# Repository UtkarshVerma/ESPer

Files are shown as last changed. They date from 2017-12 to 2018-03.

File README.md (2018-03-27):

# ESPer

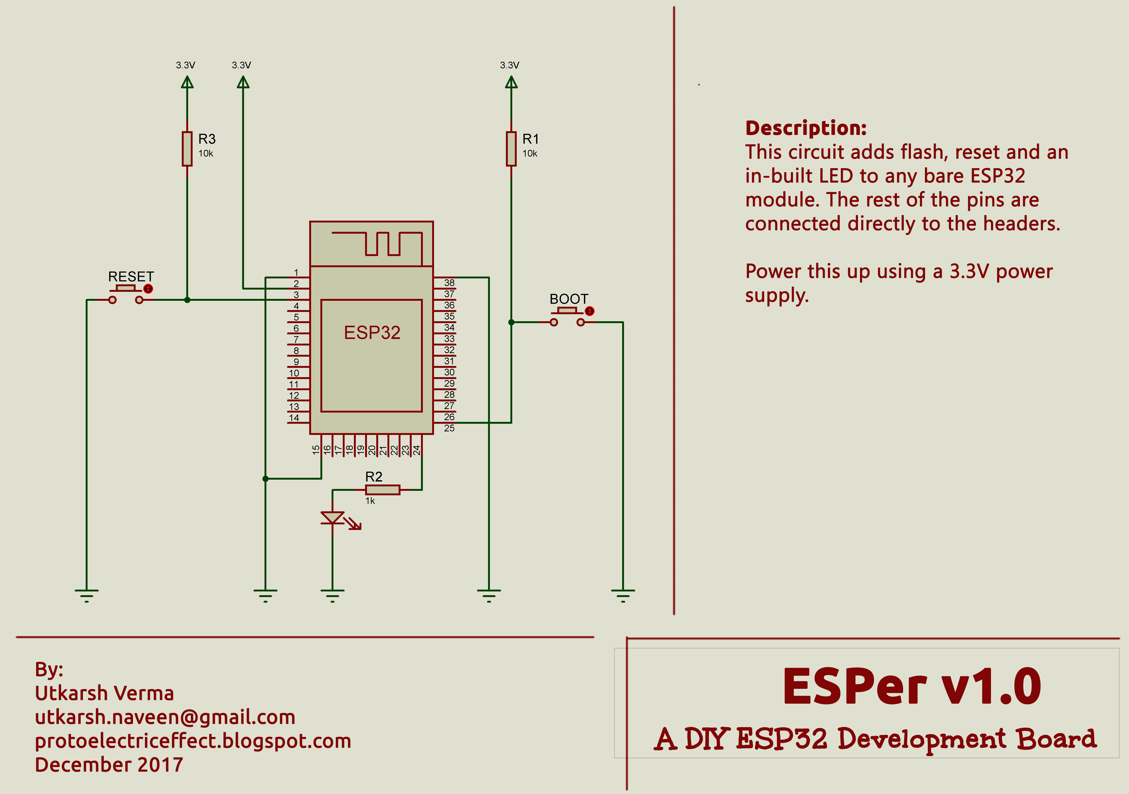
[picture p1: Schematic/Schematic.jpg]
The schematic


ESPer is a DIY ESP32 breakout board which can be easily made at home using commonly available components, because the PCB is one-sided. It 
is also breadboardable, portable and powered through a 3.3V power supply.

This repository is for storing the files related to ESPer Development board. For more info regarding this board, visit:

[DIY ESP32 Development Board - ESPer](https://www.instructables.com/id/DIY-ESP32-Development-Board-ESPer/)

You can also check out its testing video on YouTube:
[ESPer Blink Test](https://youtu.be/wEwncJ5RnA0)

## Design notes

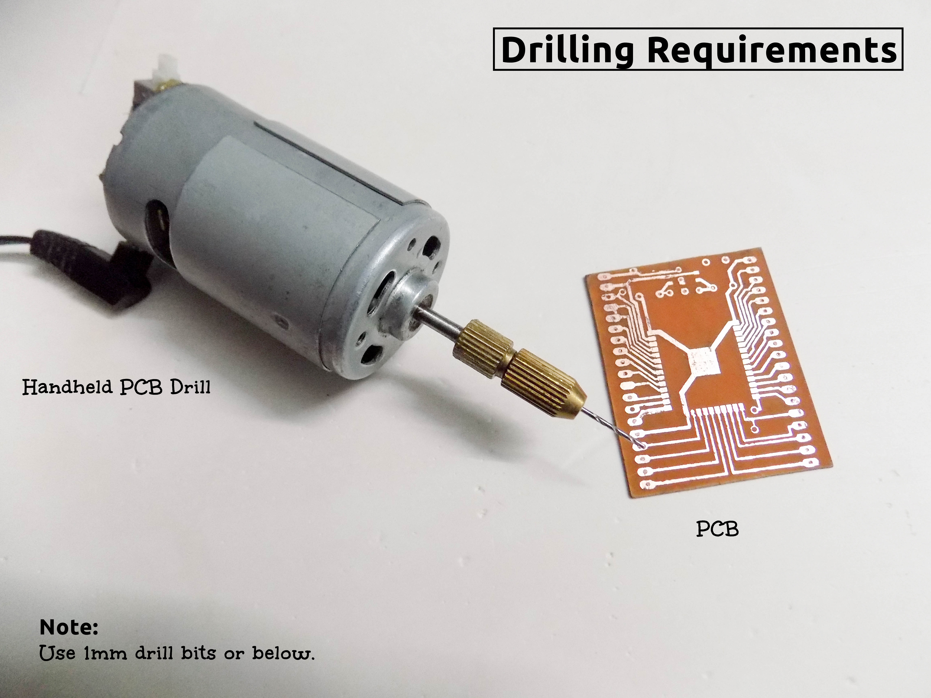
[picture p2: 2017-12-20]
Edited Pictures/Drilling Requirements.jpg

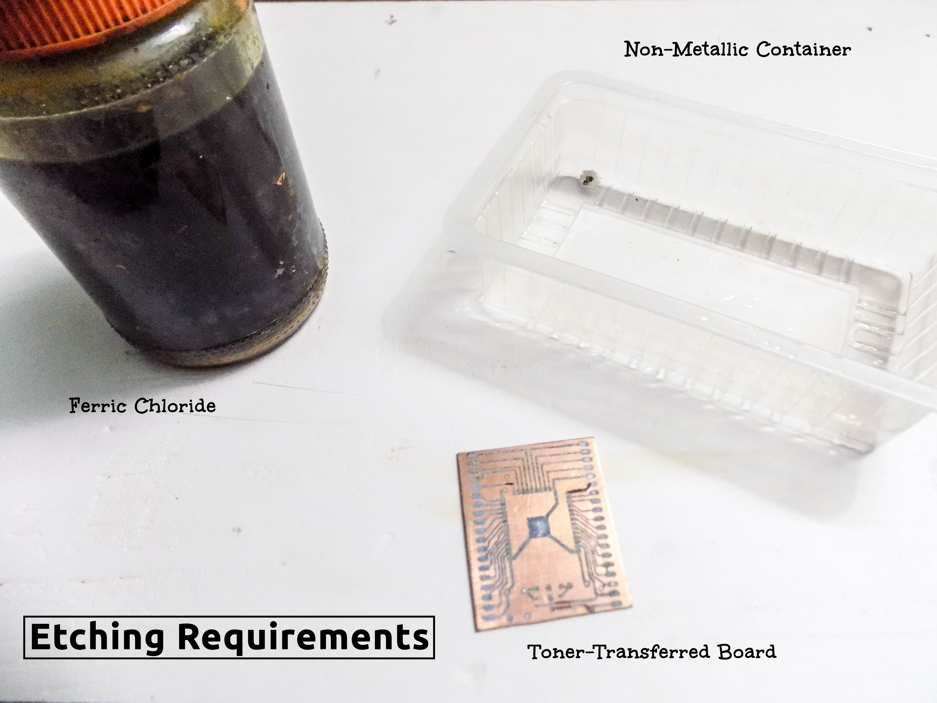
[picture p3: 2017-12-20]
Edited Pictures/Etching Requirements.jpg

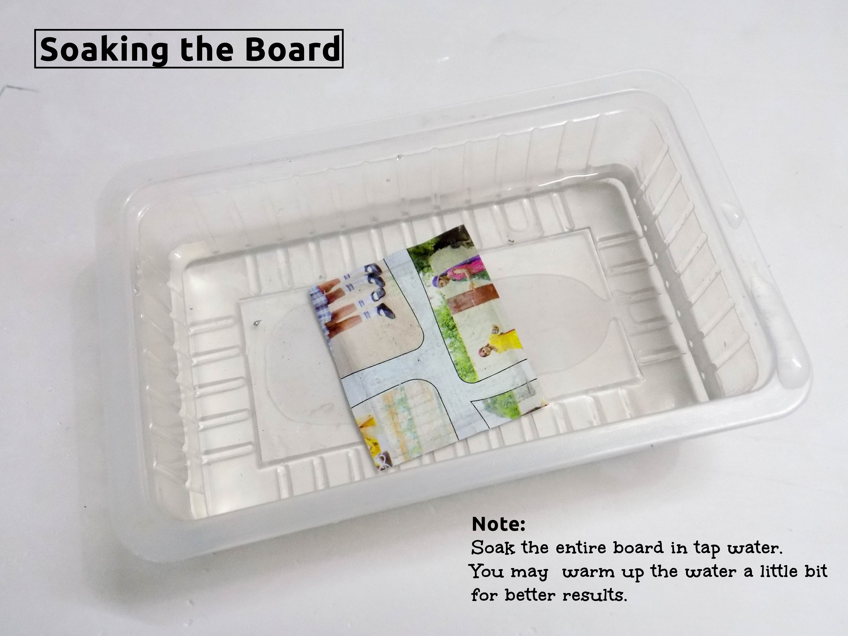
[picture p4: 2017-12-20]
Edited Pictures/Soaking the Board.jpg

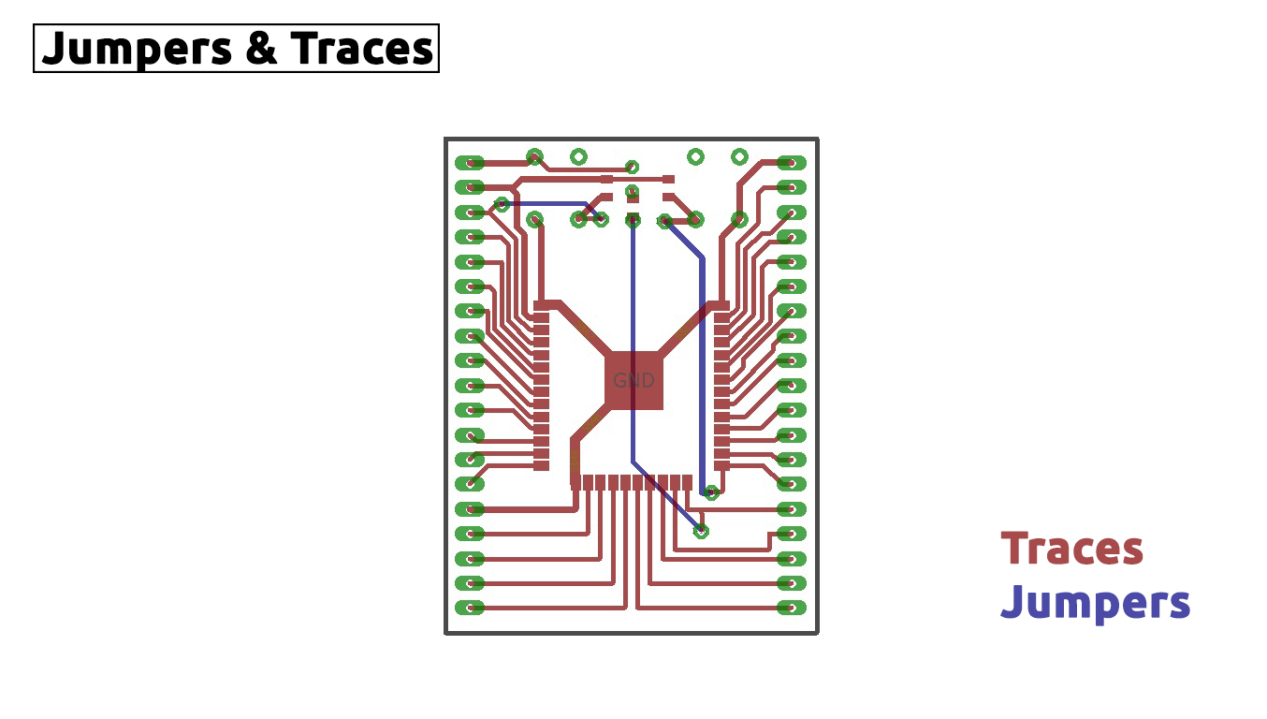
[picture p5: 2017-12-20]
PCB Files/Jumpers & Traces.jpg

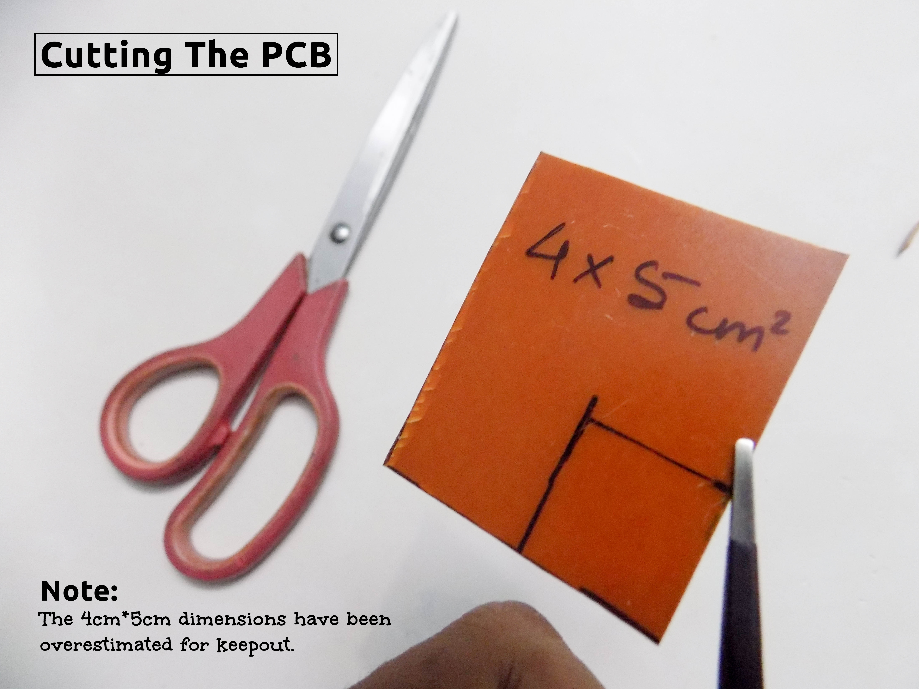
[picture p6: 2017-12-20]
Edited Pictures/Cutting The PCB.jpg

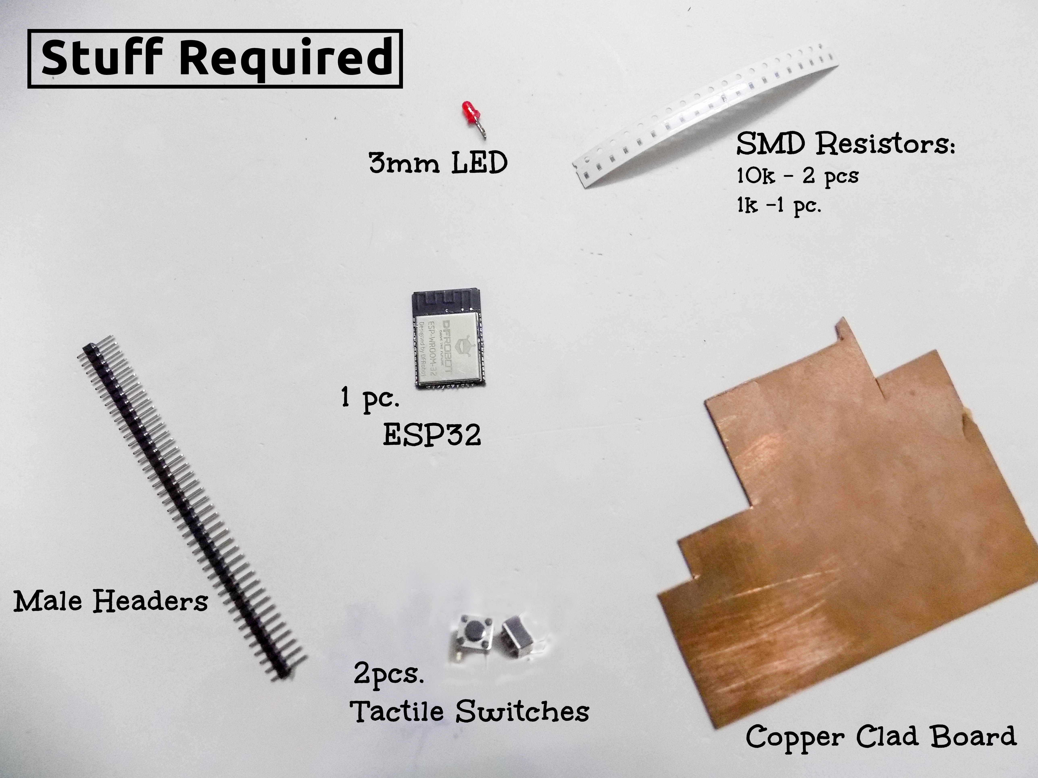
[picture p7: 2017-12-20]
Edited Pictures/Stuff Required.jpg

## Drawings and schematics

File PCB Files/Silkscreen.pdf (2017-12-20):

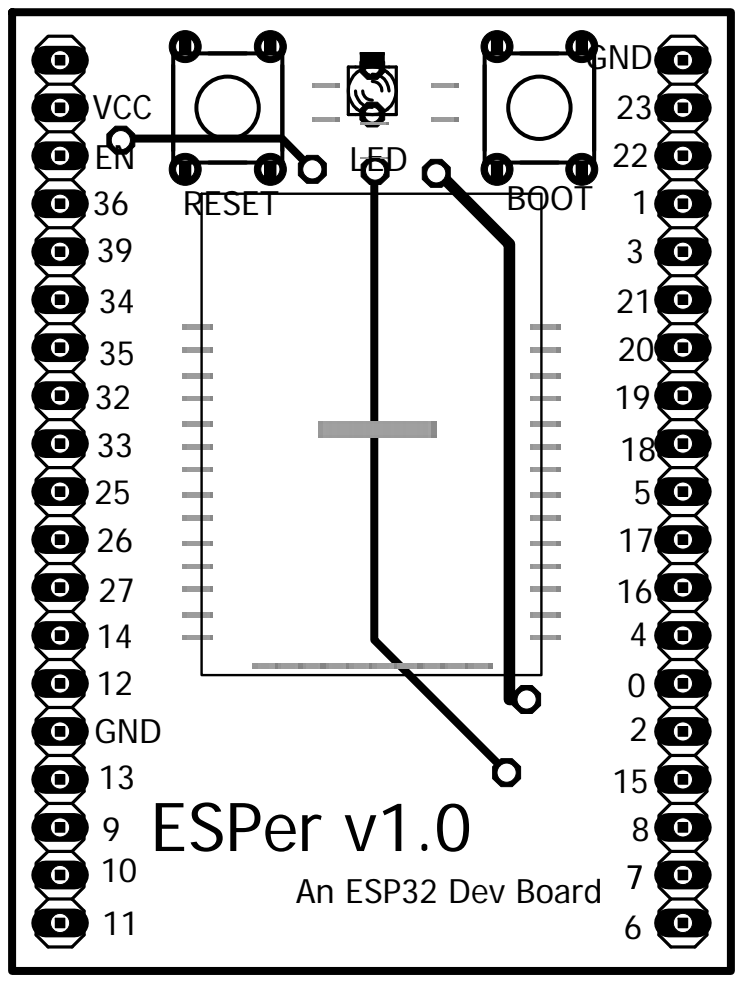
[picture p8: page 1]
VCC EN; 34 35 32 33 25 26 27 14 12 GND 13 9 10; GND; RESET; BOOT; ESPer v1.0; LED

An ESP32 Dev Board

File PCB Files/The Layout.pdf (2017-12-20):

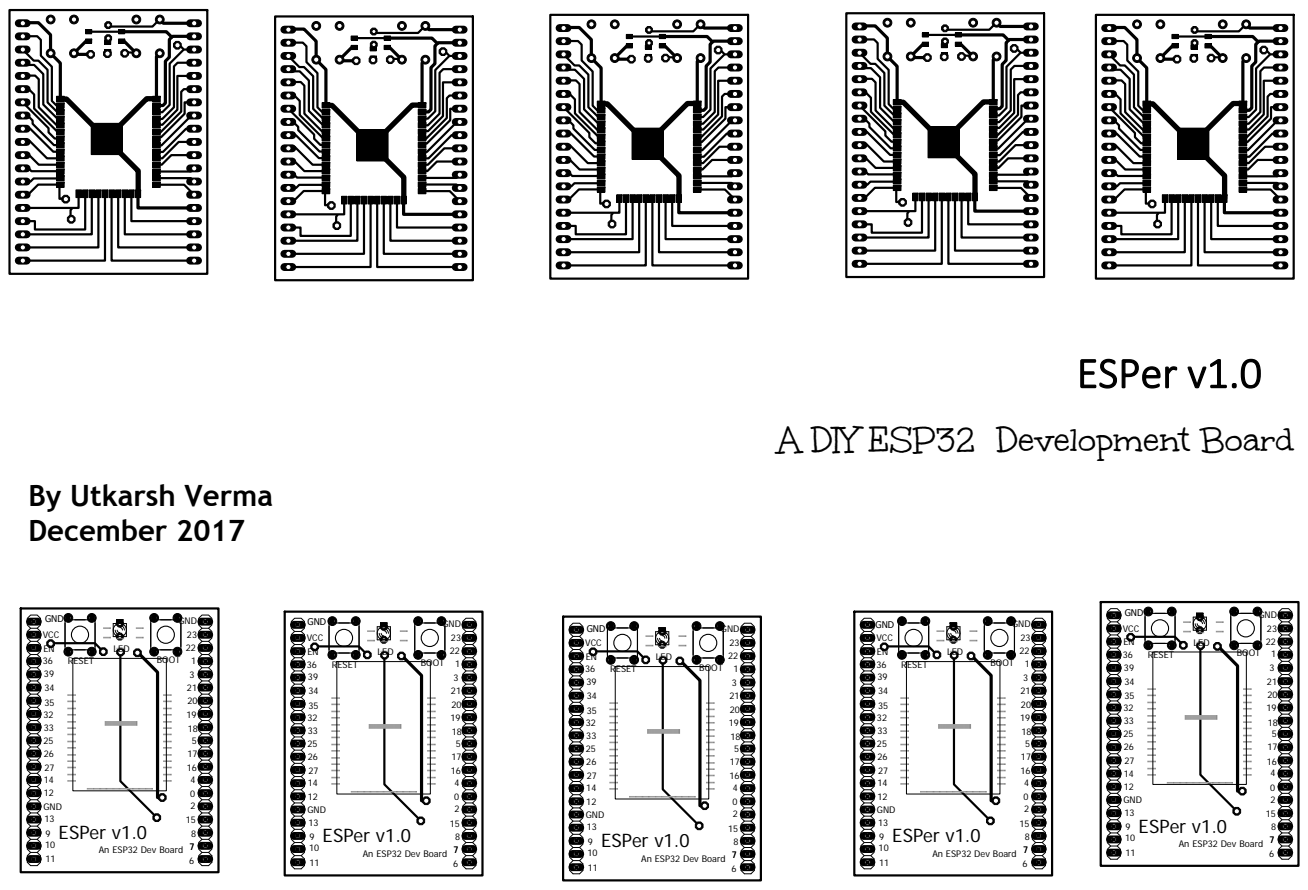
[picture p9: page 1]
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

A DIY ESP32 Development Board

By Utkarsh Verma
December 2017

An ESP32 Dev Board

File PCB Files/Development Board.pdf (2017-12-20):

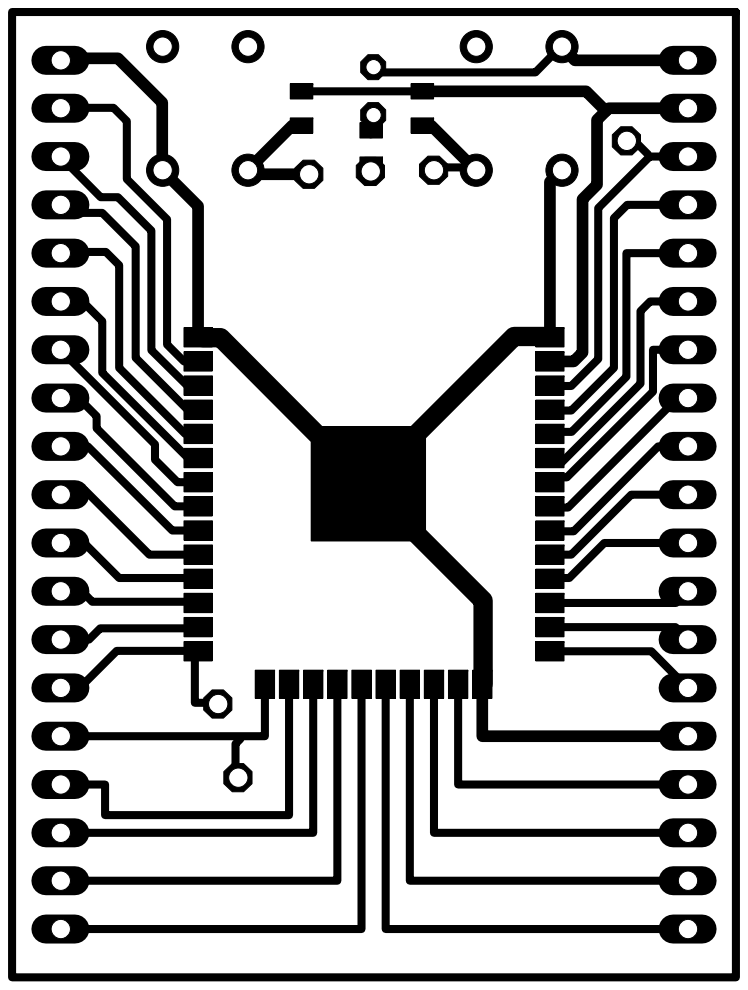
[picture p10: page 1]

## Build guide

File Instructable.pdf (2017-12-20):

instructables

## DIY ESP32 Development Board - ESPer

by UtkarshVerma

So recently I had been reading about a lot of IoTs(Internet of Things) and trust me, I just couldn't wait to test one of these wonderful devices, with the ability to connect to the internet, myself and get my hands on work. Luckily the opportunity arose, thanks to DFRobot, and I was provided with ESP32, a powerful, hybrid and an awesome module.

To begin with, I purposely asked the DFRobot team to send me the ESP32 module rather than the development board because I couldn't let the thrill of skillful get past my hands. And hence, here we are, making ourselves our own development board for ESP32.

My main aims for this board were as follows:

The development board must be breadboard-friendly.
It must have EN(Reset) and FLASH tactile switches.
One sided PCB layout.

I chose one sided layout because not everyone has access to double sided PCBs, me being one those people.

No in-built UART communication circuitry.

This was quite a trade-off because the one sided layout could only give enough space. Therefore we'll be using USB to TTL Converters externally to flash it.

Like Arduino, I wanted to have an in-built LED for reducing recurring LED wirings.
Compact, yet easy to solder and make.
A detailed silkscreen.
Use the GND solder pad in ESP32 for better heat loss.

Fortunately I was able to fulfill all the above mentioned aims after designing various PCB layouts. That being said, let's proceed with the instructable.

DIY ESP32 Development Board - ESPer: Page 1

### Step 1: Gather Around Some Stuff

Making this development board requires only the basic articles if you exclude the SMD resistors and of course,

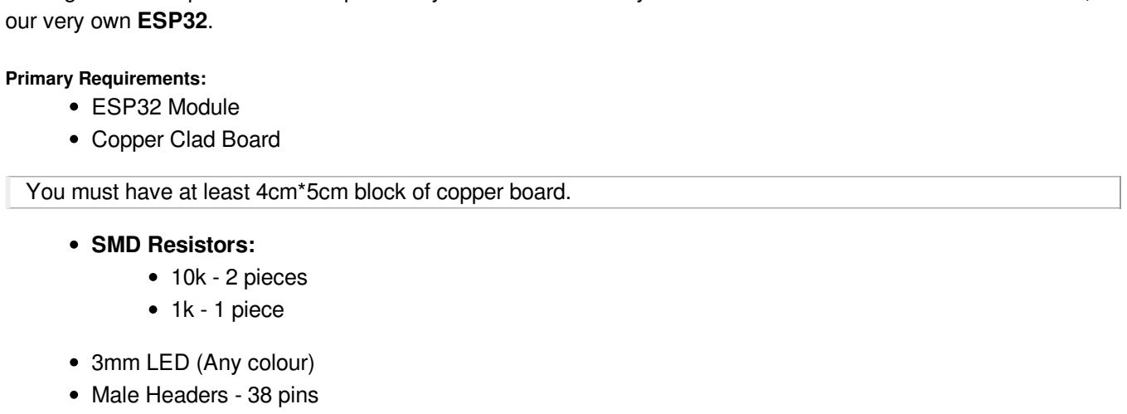
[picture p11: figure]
our very own ESP32.; Primary Requirements: ESP32 Module Copper Clad Board; SMD Resistors: 10k - 2 pieces 1k - 1 piece; 3mm LED (Any colour) Male Headers - 38 pins

You must have at least 4cm*5cm block of copper board.

Tactile Switch - 2 pieces

Secondary Requirements:
Soldering Iron

I'm using the soldering kit provided by DFRobot. It was very handy in making this instructable.

PCB Drill

Don't have one? Why not try making one yourself! Here's how

Ferric Chloride

This will be used for etching purposes.

Sanding Paper - Zero Grade Clothes Iron
Any PCB Cutting Tool
Double-Sided Tape
A Permanent Marker
Scissors
Acetone

I wanted to do things cleanly, if you don't then you may simply skip this.

I have attached the board files of eagle for giving you modification freedom.

That's all for the requirements, if you have all the above mentioned stuff, proceed further.

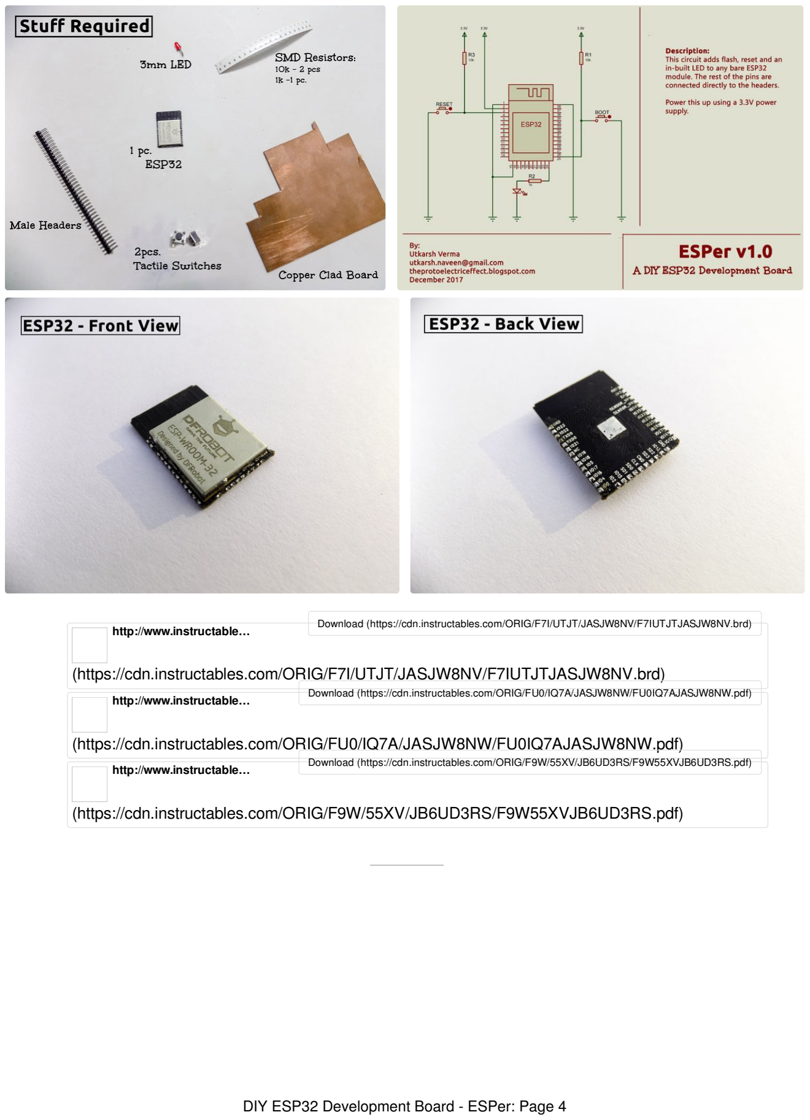
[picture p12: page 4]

http://www.instructables…

(https://cdn.instructables.com/ORIG/F7I/UTJT/JASJW8NV/F7IUTJTJASJW8NV.brd)

Download (https://cdn.instructables.com/ORIG/F7I/UTJT/JASJW8NV/F7IUTJTJASJW8NV.brd)

http://www.instructables…

(https://cdn.instructables.com/ORIG/FU0/IQ7A/JASJW8NW/FU0IQ7AJASJW8NW.pdf)

Download (https://cdn.instructables.com/ORIG/FU0/IQ7A/JASJW8NW/FU0IQ7AJASJW8NW.pdf)

http://www.instructables…

(https://cdn.instructables.com/ORIG/F9W/55XV/JB6UD3RS/F9W55XVJB6UD3RS.pdf)

Download (https://cdn.instructables.com/ORIG/F9W/55XV/JB6UD3RS/F9W55XVJB6UD3RS.pdf)

### Step 2: Making the PCB

I'll be making the PCB using the remedial Toner Transfer method. Print out the attached PDF on the requirements step on a glossy paper, the one that feels good to touch. Once you have a crisp printout of the layout on a (white)glossy paper, then there's no more stopping you, therefore begin with the PCB manufacture.

detail in another one of my instructables.

Making PCBs at Home

I'm stressing on the glossy paper being white because later on we'll be cutting off the silkscreen from it. I don't have a white glossy paper, therefore I took two printouts of the same layout.

The PCB manufacturing process has been covered in

I'm attaching the pictures of how this PCB was made, above.

For drilling, use 1mm drill bits or below.

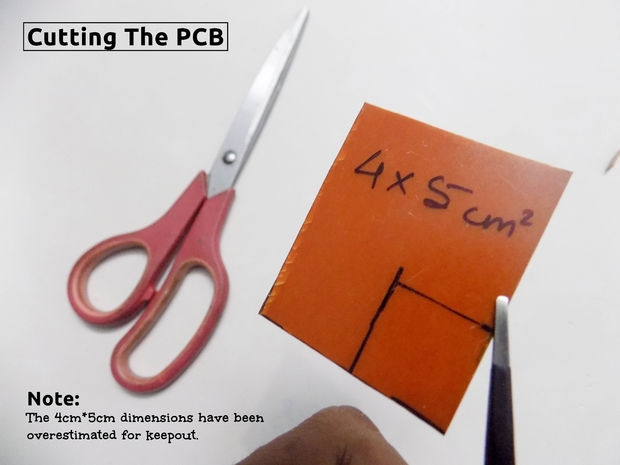
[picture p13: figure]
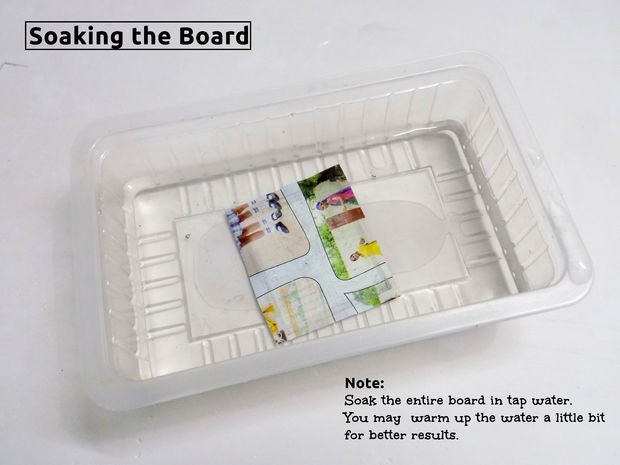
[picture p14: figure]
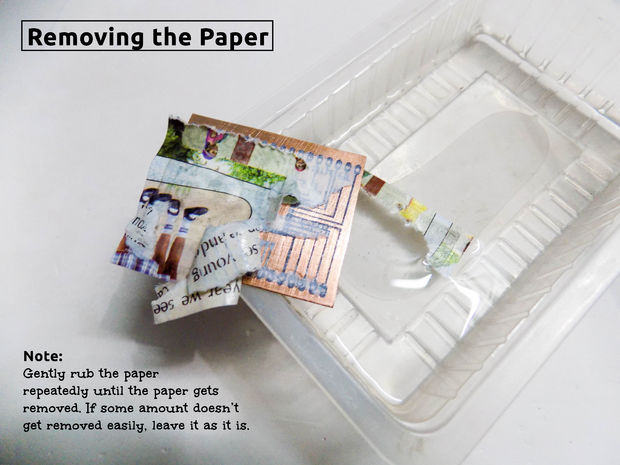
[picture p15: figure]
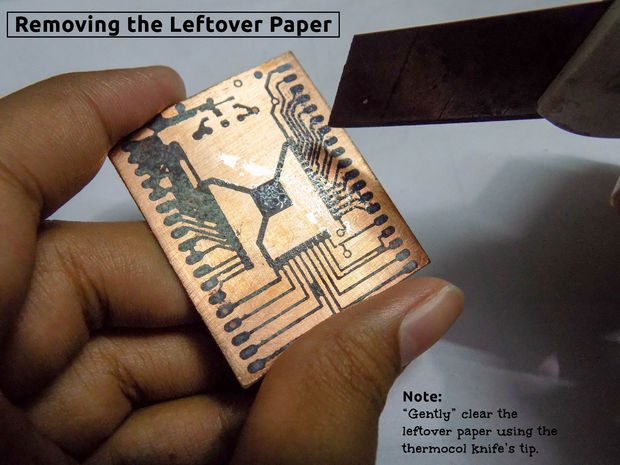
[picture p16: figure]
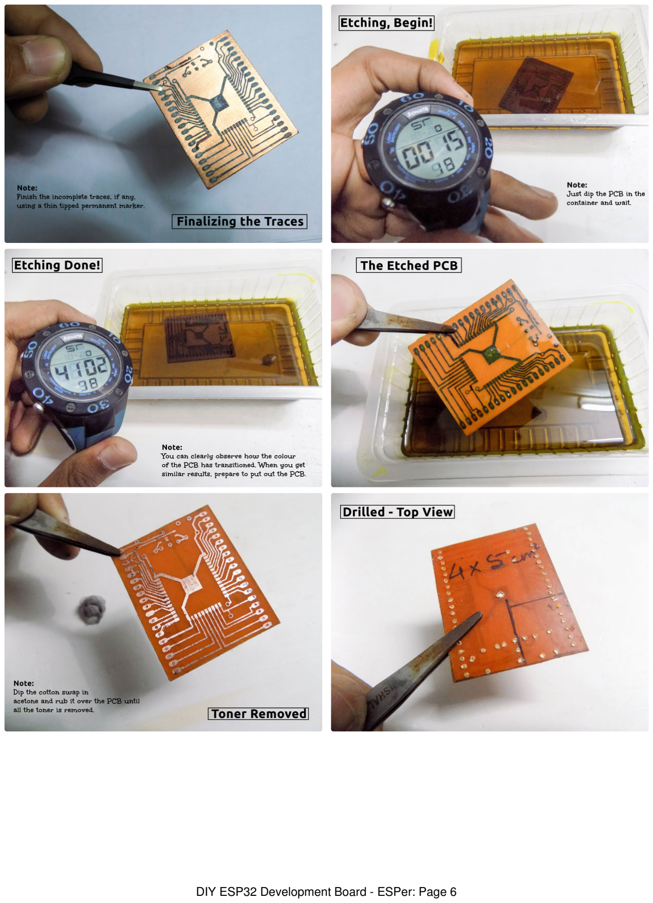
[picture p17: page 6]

### Step 3: Soldering the Components

Begin by soldering the ESP32 onto the PCB. Certain things to be kept in mind while soldering this challenging, yet fun module are stated below.

Alignment of the module with the solder pads, the first step, is the most crucial part of the whole thing. Mess this up and you'll suffer non-working GPIOs and maybe even a non-working module! Use pointed soldering tips to prevent dismantling of traces or solder pads due to overheating. While soldering the ESP32 module, solder the diagonal pads first so that the chip doesn't mess up its alignment.
Solder the GND pad of ESP32 by heating the solder in that pad through the hole drilled in the centre. This will heat the solder on the GND pad of ESP32 and merge it with the GND pad on the PCB.

Once you're done with that, solder all the components one by one in their respective places by referring to the above pictures. The correct order for soldering the components is:

1. ESP32
2. SMD Resistors
3. Tactile Switches
4. LED
5. Jumpers
6. Male Headers

The jumpers are three in number. In the screenshot of eagle layout posted above, the blue wires represent the jumpers. Here, enamelled wires have been used as jumpers. While soldering the headers, placing ESPer on breadboards perfectly aligns the headers.

After soldering all the components carefully and correctly, clean the whole PCB by using an old toothbrush(also useless). This removes all the excess flux. DIY ESP32 Development Board - ESPer: Page 7

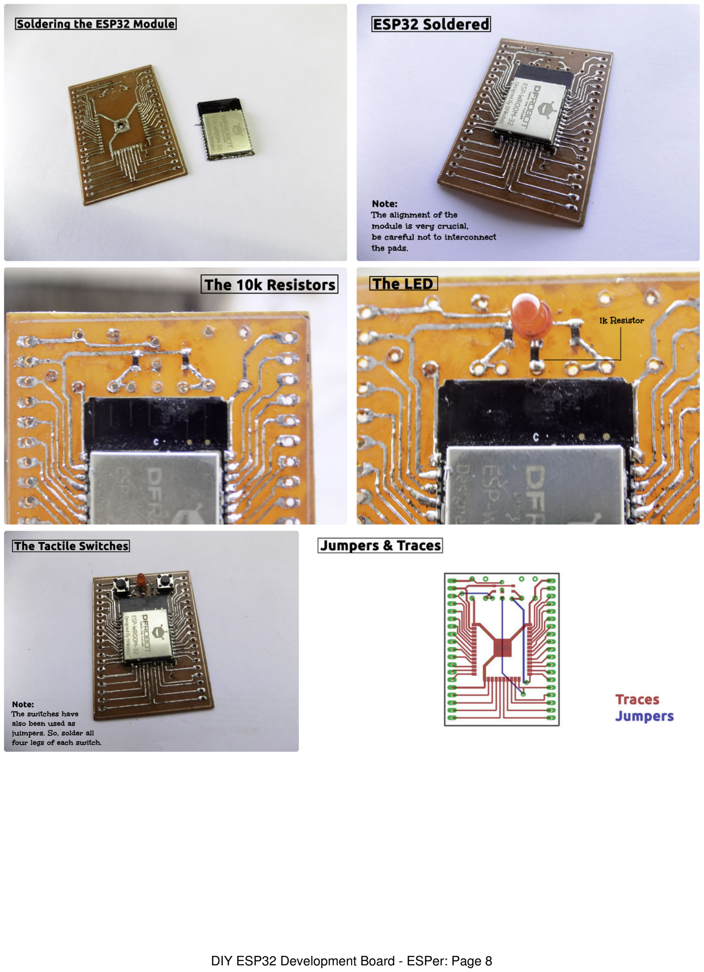
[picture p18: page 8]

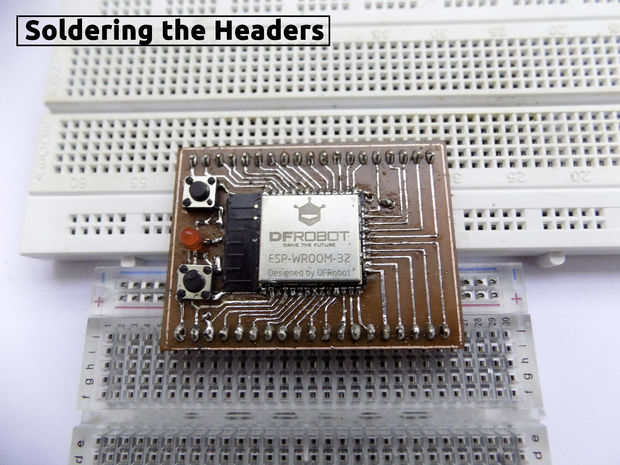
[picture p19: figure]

### Step 4: Pasting the Silkscreen

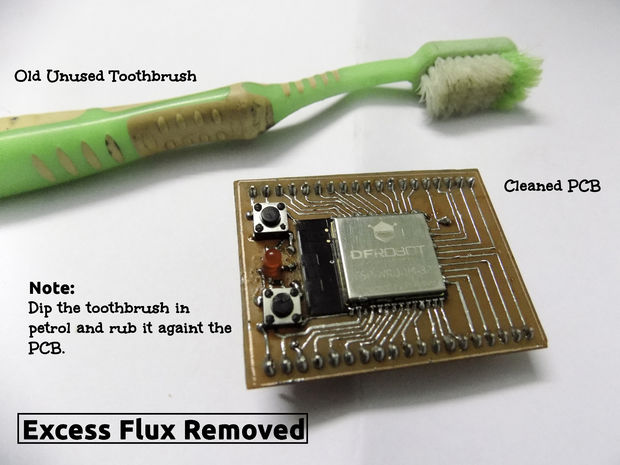
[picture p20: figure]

Now our ESPer is completely functional but it still lacks something, and that is a silkscreen. Adding this silkscreen will rid us of continuous referring to pinouts. To stick it to the the board, I'll be using double-sided tape. The silkscreen can be attained through the layout printed earlier.

If you have doubts regarding your work or wiring, this is the time for checking it. Because after following the later steps, you won't be able to modify your board in any way. Proceed with caution.

Now proceed with the silkscreen by doing the following:

Cover the entire ESPer board with double sided tape bits, except the ESP32 part.
Then align the silkscreen and paste it on the double sided tape carefully.
After that, remove the amount of paper above ESP32 to expose it, and fill the left empty spaces using hot glue.
That's all for this step. | DIY ESP32 Development Board - ESPer: Page 9

### Step 5: Congratulations!

Did all the previous steps? If yes, then congratulations because that's all for this instructable.

Now you can use your ESP32 module just like any other development board just by wiring it up with any USB to TTL Converter(even your Arduino). The wiring is simple, just power ESPer using a 3.3V power supply and make the UART connections(Rx,Tx). When using Arduino, ground the RESET pin to use

it as a TTL Converter. I'll be covering up more about ESP32 using this development board in the upcoming instructables.

I've embedded a video which shows the ESP32 handling a Blink code which I had flashed through Mongoose OS.

I've removed my silkscreen because I had to do further improvements for other projects.

You can do the same by following this instructable which covers how to use ESP32 as Arduino.

Meanwhile I'd like to thank DFRobot.com for sending me awesome stuff like the ESP32 and giving me the opportunity to tinker with them. Even words aren't enough to express my gratitude.

That's it for this instructable. If you have any doubt, feel free to comment. Don't forget to follow me if you liked this instructable. Please support me by reopening the shortened links twice or thrice.

Keep Tinkering!

By:
Utkarsh Verma

In collaboration with DFRobot.com

Thanks to Ashish Choudhary for lending his camera.

https://youtu.be/wEwncJ5RnA0

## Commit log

2017-12-20 The PCB files for ESPer
    [ESPer v1.0.brd, Silkscreen.brd]
2017-12-20 The schematic for ESPer
